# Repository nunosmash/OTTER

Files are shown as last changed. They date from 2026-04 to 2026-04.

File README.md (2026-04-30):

[README.md](https://github.com/user-attachments/files/26697365/README.md)
# OTTER

**Haptic MIDI controller** that pairs analog-feel **encoder** control with DAW integration: **Live** and **Studio** modes, **haptic** feedback, **layers** and **pages**, and a **Web Editor** (Chrome) for full configuration.

Part of the **Ash Sound Works** custom tools for live and studio — by sound artist and producer **Ash (Ahn Sunghoon)** · [GitHub](https://github.com/nunosmash) / 
[Manual](http://ashsoundworks.com/otter-manual.html)

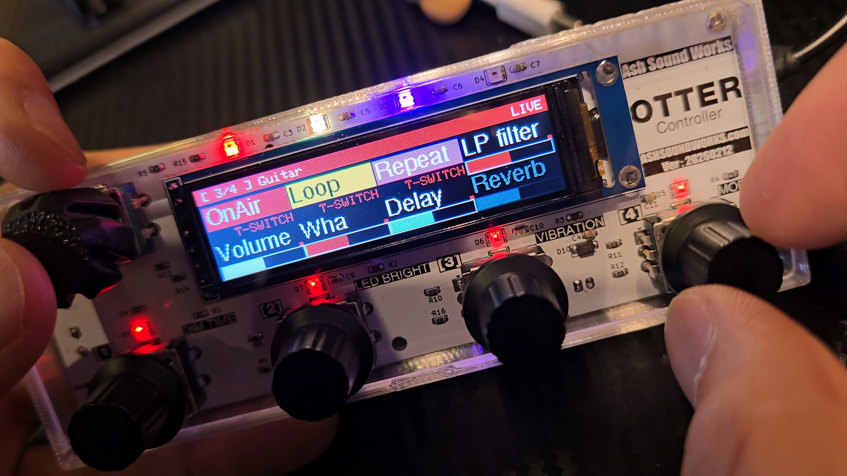
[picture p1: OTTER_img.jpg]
OTTER (https://youtu.be/qmccIaClYyg?si=hlSnW6YCaZTJ9VbL)


---

## Why OTTER?

Typical MIDI controllers struggle with the same tension: **analog pots** feel great, but mapping them to a DAW can cause **parameter jumps** encoders don’t always fix—especially when acceleration makes muscle-memory control unreliable on stage.

OTTER uses **encoders** with a **Live Mode** that maps rotation to a **fixed angular range** (like a pot), independent of spin speed, plus **haptic** cues at center (64) and at min/max (0 / 127). **Studio Mode** keeps fine resolution for production work. Bidirectional sync with the DAW and the Web Editor keeps names, colors, and lock logic aligned across sessions.

---

## Features

- **4 encoders** with push / rotate, **4 pages** — up to **32 parameter roles** (4×4×2 layers), plus multiple **global** and **button** mappings  
- **Live Mode** — rotation angle maps 1:1 with smoothing (stage-friendly, eyes-off control)  
- **Studio Mode** — speed-based acceleration for fast sweeps and fine edits  
- **Safety Lock** — auto-locks after page changes or idle; ~4 detents rotation to unlock  
- **Haptic motor** + **LED** feedback (center snap, boundary alerts); intensity: OFF / LOW / MID / HIGH  
- **USB MIDI** (class-compliant)  
- **Internal flash** + Web Editor sync for presets  
- **Web Editor** — latest **Chrome** ; connect via WebUSB  

---

## Specifications (summary)

| Item | Details |
|---|---|
| Model | OTTER |
| Controls | Global / Page encoder, Encoders 1–4 (push + rotate) |
| Pages | 4 (4 encoders × 2 layers per page → up to 32 parameters) |
| I/O | USB MIDI (class-compliant) |
| Feedback | Haptic motor, LEDs |
| Storage | Internal flash, synced with Web Editor |
| Web Editor | Chrome (latest recommended) |

---

## Basic hardware behavior

- **Rotate** — increase / decrease value  
- **Short push** — layer toggle or button action (per mapping)  
- **~4 detents rotation** — unlock **Safety Lock**  
- **Global push + bottom encoder click** — device setup (DIM time, LED brightness, vibration strength, mode)  

---

## Web Editor

1. Use **Chrome** (current version).  
2. Open the bundled **OTTER Web Editor** HTML (local file or hosted URL).  
3. Connect OTTER over USB → click **Connect** in the editor and grant device access.  
4. When the status shows **Connected**, edit and sync parameters, names, and colors.  

Editor path in the site package: `otter/OTTER Web Editor.html`

---

## Firmware update (.uf2)

OTTER uses **UF2** drag-and-drop firmware (RP2040 bootloader appears as **RPI-RP2**).

1. Connect OTTER with a **data** USB cable.  
2. Hold **Button 1** and **Button 4** together for **3+ seconds** until the **RPI-RP2** drive appears.  
3. Copy the correct **`.uf2`** file onto the drive; the device reboots when done.  

---

## Repository contents

Depending on branch or release, this repo may include:

- Firmware source  
- Web Editor assets  
- Build and flash instructions  

For full mode behavior, haptics detail, and troubleshooting, see **`otter-manual.html`** in the Ash Sound Works website bundle — add your public URL once deployed.

---

| Category | Component Description | Qty |
| :--- | :--- | :---: |
| **MCU** | Raspberry Pi Pico 2 (RP2350) | 1 |
| **Display** | 2.25" TFT LCD (ST7789, 76x284 Resolution) | 1 |
| **Encoders (Primary)** | Bourns PEC11R-4015F-S0024 | 4 |
| **Encoder (Menu)** | EC11 Rotary Encoder w/ Push Switch (Detent) | 1 |
| **Haptics** | 3V 10mm Mini Vibration Coin Motor | 1 |
| **Connectors** | PJ-320A 3.5mm Stereo Jack | 1 |
| **Capacitors** | 100μF Electrolytic Capacitor | 2 |
| **Enclosure** | 121 x 43 x 2mm Clear Acrylic Top Plate | 1 |
| **Hardware** | Custom Encoder Knobs | 5 |
| **Hardware** | Brass Heat-Set Insert Nuts (M2x2x3.2) | 4 |
| **Hardware** | M2 Phillips Head Screws (M2x4) | 4 |

---

## Documentation

- Full manual: `otter-manual.html`  
- Web Editor: `otter/OTTER Web Editor.html`  
- Other projects: [github.com/nunosmash](https://github.com/nunosmash)

---

## Disclaimer

- Use a **data-capable** USB cable for editor and firmware updates.  
- DIY builds: follow safe practice for power and assembly.

---

## License

See the `LICENSE` file in the repository root.

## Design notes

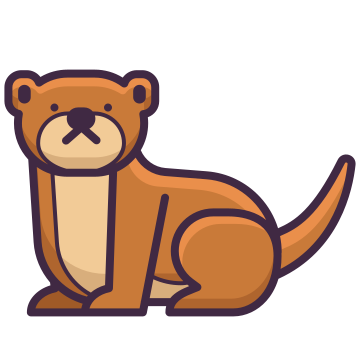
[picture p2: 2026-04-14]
Editor/otter.png

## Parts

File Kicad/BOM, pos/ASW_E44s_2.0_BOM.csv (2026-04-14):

Id | 지정자 | 풋프린트 | 수량 | 지정 | 공급자와 참조
1 | D9,D2,D3,D5,D4,D7,D1,D6,D8 | LED_WS2812B-2020_PLCC4_2.0x2.0mm | 9 | WS2812B-2020
2 |  |  | 1
3 | J3 | PJ-320A | 1 | AudioJack4
4 | J1 | PinHeader_1x08_P2.54mm_Vertical ST7789_76x284 | 1 | ST7789_76x284
5 | R2,R15,R3,R5,R4,R1 | R_0603_1608Metric | 6 | 150R
6 | Enc5 | RotaryEncoder_Alps_EC11E-Switch_Vertical_H20mm | 1 | EC11
7 | R14,R13,R10,R7,R8,R6,R16,R12,R11,R9 | R_0603_1608Metric | 10 | 330R
8 | Enc4,Enc1,Enc3,Enc2 | RotaryEncoder_Alps_EC11E-Switch_Vertical_H20mm | 4 | PEC11R-4015F-S0024
9 | C10,C9,C3,C4,C8,C11,C5,C7,C12,C6 | C_0603_1608Metric | 10 | 100n
10 | R18 | R_0603_1608Metric | 1 | 10k
11 | R17 | R_0603_1608Metric | 1 | 1k
12 | Q1 | SOT-23 | 1 | SS8050
13 | D10 | D_SOD-123 | 1 | SM4007
14 | R20 | R_0603_1608Metric | 1 | 30
15 | R19 | R_0603_1608Metric | 1 | 10
16 | J2 | JST_PH_B2B-PH-K_1x02_P2.00mm_Vertical | 1 | Motor_Socket
17 | C1,C2 | CP_Radial_D8.0mm_P3.50mm | 2 | 220uF
18 | A1 | RaspberryPi_Pico_Common_THT2 | 1 | RaspberryPi_Pico2

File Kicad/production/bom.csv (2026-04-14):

Designator | Footprint | Quantity | Value | LCSC Part #
 |  | 1
A1 | RaspberryPi_Pico_Common_THT2 | 1 | RaspberryPi_Pico2
C1, C2 | CP_Radial_D8.0mm_P3.50mm | 2 | 220uF
C10, C11, C12, C3, C4, C5, C6, C7, C8, C9 | 0603 | 10 | 100n
D1, D2, D3, D4, D5, D6, D7, D8, D9 | LED_WS2812B-2020_PLCC4_2.0x2.0mm | 9 | WS2812B-2020
D10 | D_SOD-123 | 1 | SM4007
ENC1, ENC2, ENC3, ENC4 | RotaryEncoder_Alps_EC11E-Switch_Vertical_H20mm | 4 | PEC11R-4015F-S0024
ENC5 | RotaryEncoder_Alps_EC11E-Switch_Vertical_H20mm | 1 | EC11
J1 | PinHeader_1x08_P2.54mm_Vertical ST7789_76x284 | 1 | ST7789_76x284
J2 | JST_PH_B2B-PH-K_1x02_P2.00mm_Vertical | 1 | Motor_Socket
J3 | PJ-320A | 1 | AudioJack4
Q1 | SOT-23 | 1 | SS8050
R1, R15, R2, R3, R4, R5 | 0603 | 6 | 150R
R10, R11, R12, R13, R14, R16, R6, R7, R8, R9 | 0603 | 10 | 330R
R17 | 0603 | 1 | 1k
R18 | 0603 | 1 | 10k
R19 | 0603 | 1 | 10
R20 | 0603 | 1 | 30

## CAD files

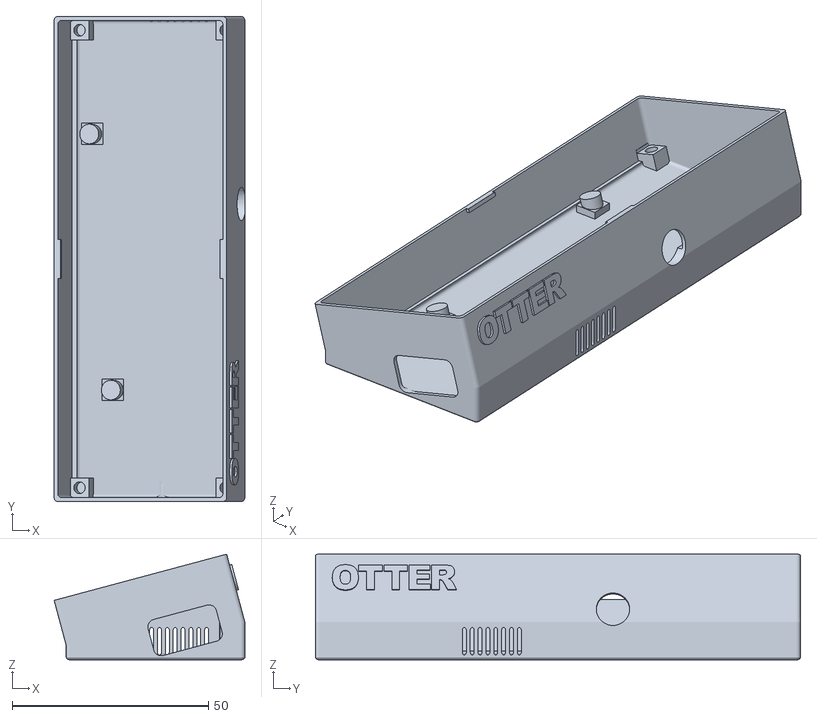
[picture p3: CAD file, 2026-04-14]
Case/OTTER case3 - 2.stl
48.6 x 123.5 x 26.9

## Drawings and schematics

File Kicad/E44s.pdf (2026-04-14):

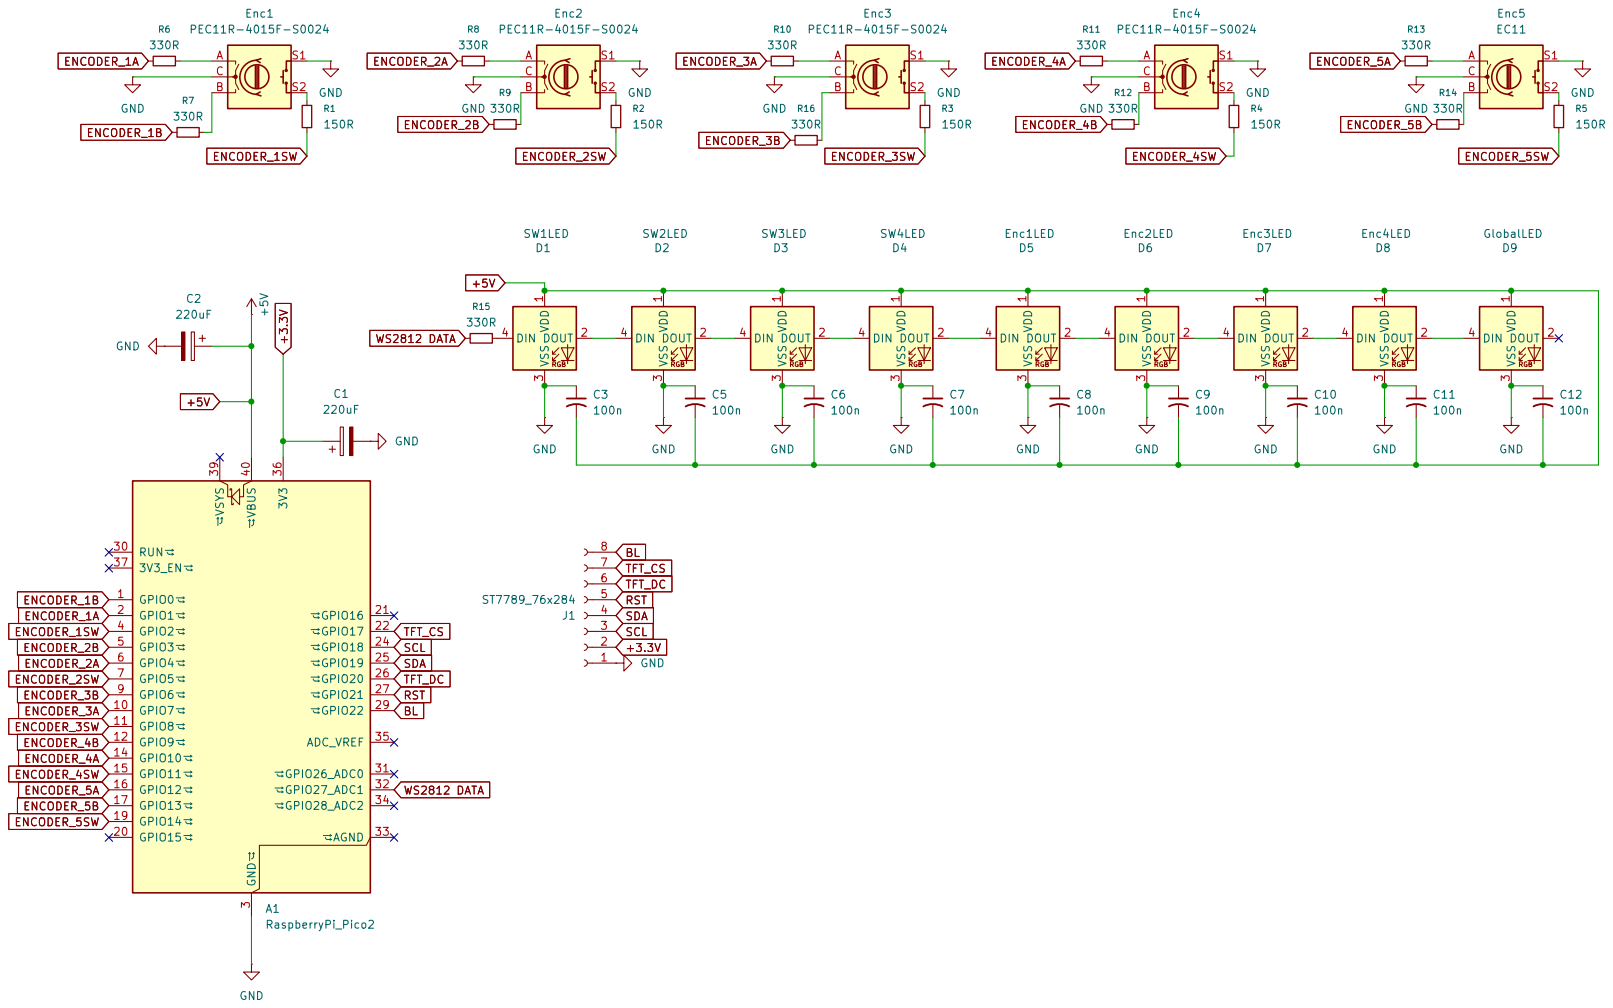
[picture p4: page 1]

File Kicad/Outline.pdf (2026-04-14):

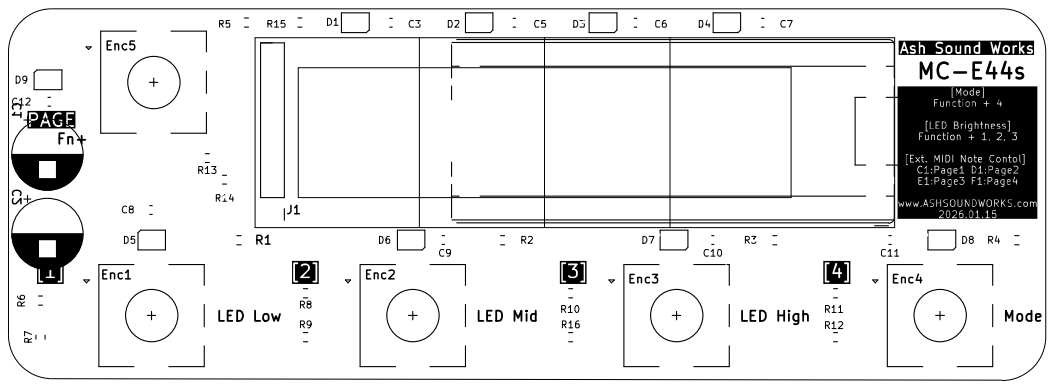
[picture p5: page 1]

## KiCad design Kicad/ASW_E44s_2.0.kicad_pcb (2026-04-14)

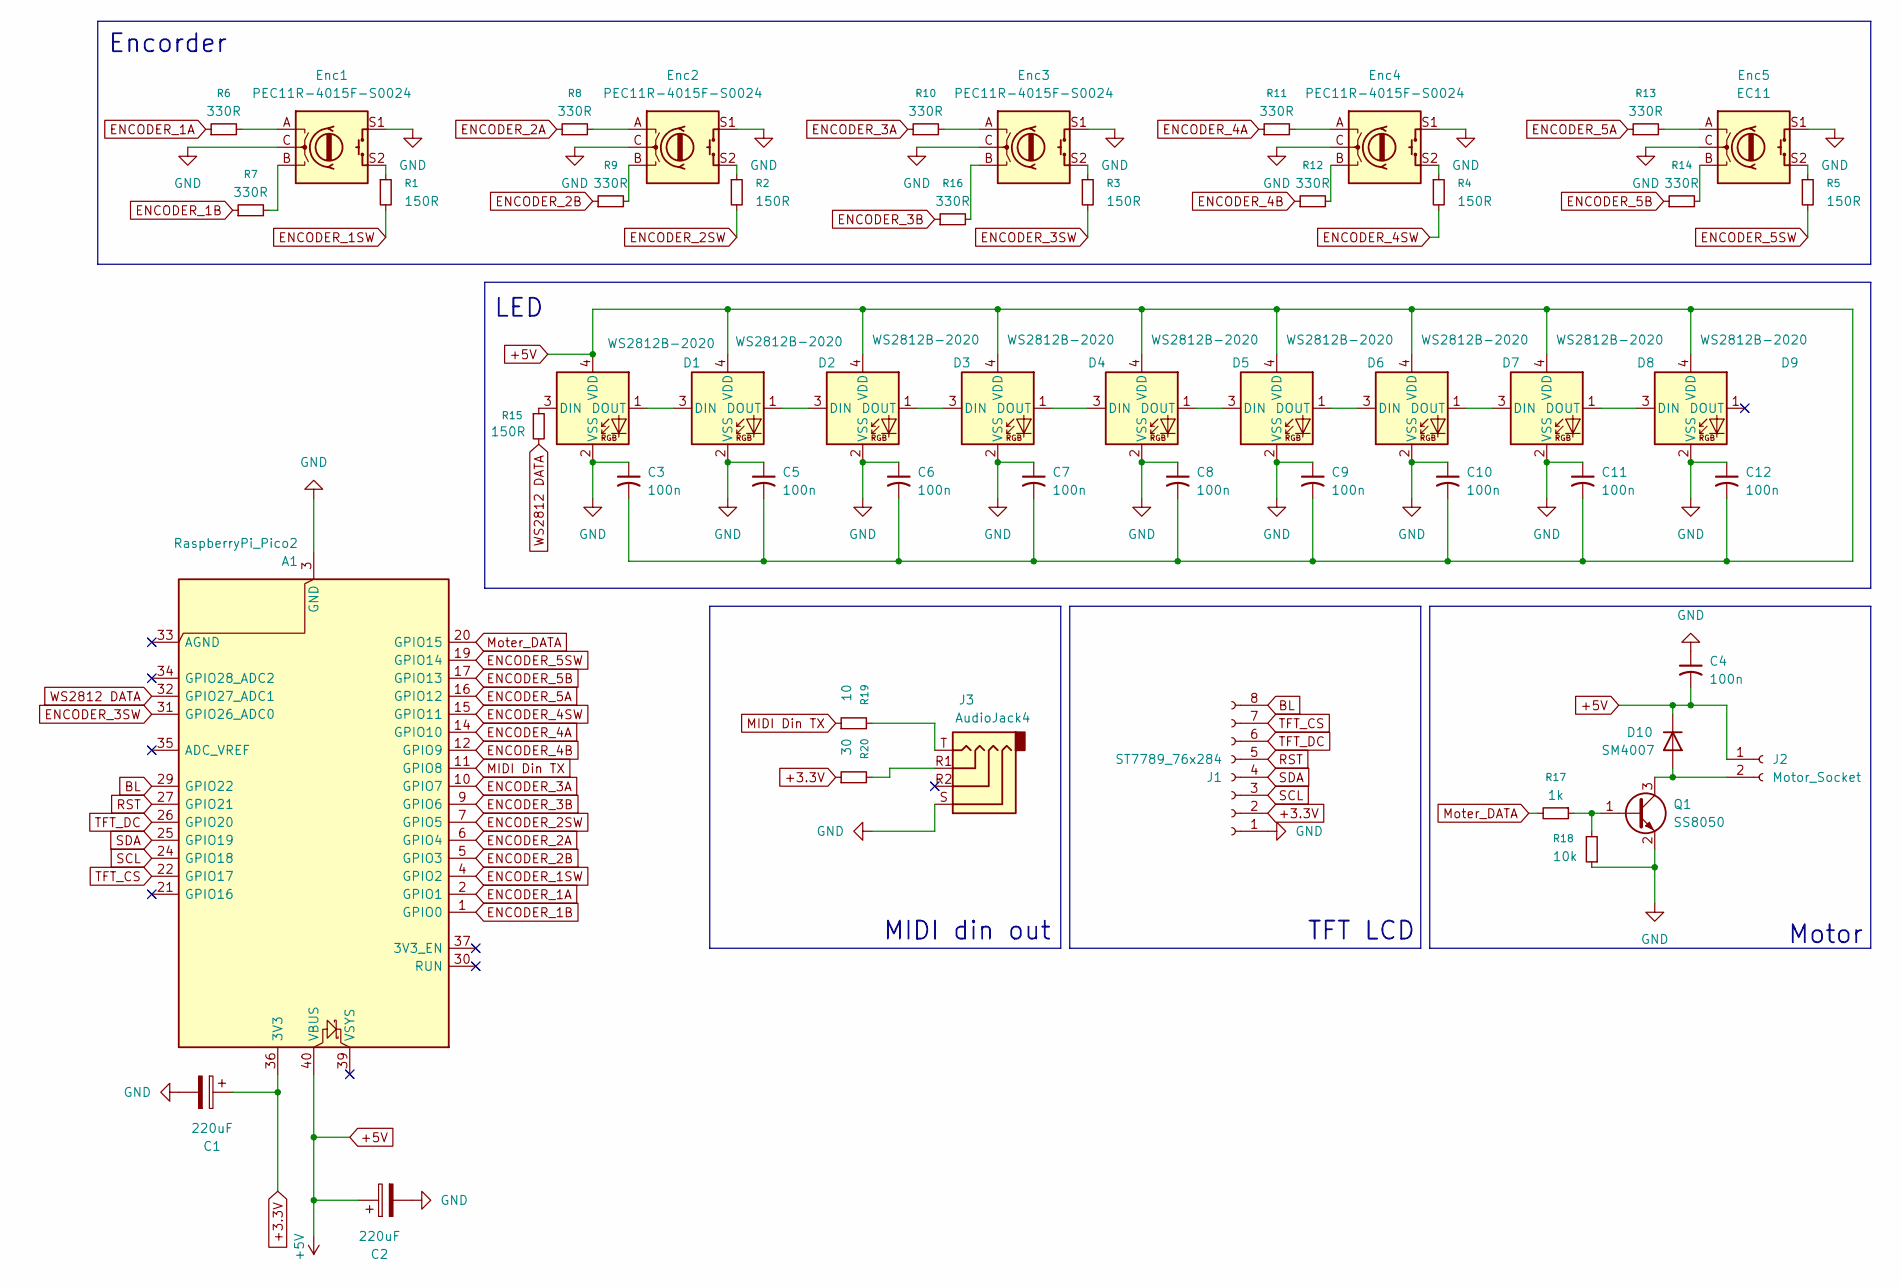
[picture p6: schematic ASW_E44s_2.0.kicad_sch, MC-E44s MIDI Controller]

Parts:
A1: RaspberryPi_Pico2; RaspberryPi_Pico_Common_THT2
C1, C2: 220uF; CP_Radial_D8.0mm_P3.50mm
C3, C4, C5, C6, C7, C8, C9, C10, C11, C12: 100n; C_0603_1608Metric
D1, D2, D3, D4, D5, D6, D7, D8, D9: WS2812B-2020; LED_WS2812B-2020_PLCC4_2.0x2.0mm
D10: SM4007; D_SOD-123
Enc1, Enc2, Enc3, Enc4: PEC11R-4015F-S0024; RotaryEncoder_Alps_EC11E-Switch_Vertical_H20mm
Enc5: EC11; RotaryEncoder_Alps_EC11E-Switch_Vertical_H20mm
J1: ST7789_76x284; PinHeader_1x08_P2.54mm_Vertical ST7789_76x284
J2: Motor_Socket; JST_PH_B2B-PH-K_1x02_P2.00mm_Vertical
J3: AudioJack4; PJ-320A
Q1: SS8050; SOT-23
R1, R2, R3, R4, R5, R15: 150R; R_0603_1608Metric
R6, R7, R8, R9, R10, R11, R12, R13, R14, R16: 330R; R_0603_1608Metric
R17: 1k; R_0603_1608Metric
R18: 10k; R_0603_1608Metric
R19: 10; R_0603_1608Metric
R20: 30; R_0603_1608Metric

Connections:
+3.3V: A1.36 (3V3), C1.1, J1.2, R20.1
+5V: A1.40 (VBUS), C2.1, C3.2, C4.2, C5.2, C6.2, C7.2, C8.2, C9.2, C10.2, C11.2, C12.2, D1.4 (VDD), D2.4 (VDD), D3.4 (VDD), D4.4 (VDD), D5.4 (VDD), D6.4 (VDD), D7.4 (VDD), D8.4 (VDD), D9.4 (VDD), D10.1 (K), J2.1
BL: A1.29 (GPIO22), J1.8
ENCODER_1A: A1.2 (GPIO1), R6.1
ENCODER_1B: A1.1 (GPIO0), R7.1
ENCODER_1SW: A1.4 (GPIO2), R1.2
ENCODER_2A: A1.6 (GPIO4), R8.1
ENCODER_2B: A1.5 (GPIO3), R9.1
ENCODER_2SW: A1.7 (GPIO5), R2.2
ENCODER_3A: A1.10 (GPIO7), R10.1
ENCODER_3B: A1.9 (GPIO6), R16.1
ENCODER_3SW: A1.31 (GPIO26_ADC0), R3.2
ENCODER_4A: A1.14 (GPIO10), R11.1
ENCODER_4B: A1.12 (GPIO9), R12.1
ENCODER_4SW: A1.15 (GPIO11), R4.2
ENCODER_5A: A1.16 (GPIO12), R13.1
ENCODER_5B: A1.17 (GPIO13), R14.1
ENCODER_5SW: A1.19 (GPIO14), R5.2
GND: A1.3 (GND), A1.8 (GND), A1.13 (GND), A1.18 (GND), A1.23 (GND), A1.28 (GND), A1.38 (GND), C1.2, C2.2, C3.1, C4.1, C5.1, C6.1, C7.1, C8.1, C9.1, C10.1, C11.1, C12.1, D1.2 (VSS), D2.2 (VSS), D3.2 (VSS), D4.2 (VSS), D5.2 (VSS), D6.2 (VSS), D7.2 (VSS), D8.2 (VSS), D9.2 (VSS), Enc1.C, Enc1.MP, Enc1.S1, Enc2.C, Enc2.MP, Enc2.S1, Enc3.C, Enc3.MP, Enc3.S1, Enc4.C, Enc4.MP, Enc4.S1, Enc5.C, Enc5.MP, Enc5.S1, J1.1, J3.S, Q1.2 (E), R18.1
MIDI Din TX: A1.11 (GPIO8), R19.1
Moter_DATA: A1.20 (GPIO15), R17.2
unnamed: D1.3 (DIN), R15.1
unnamed: D1.1 (DOUT), D2.3 (DIN)
unnamed: D2.1 (DOUT), D3.3 (DIN)
unnamed: D3.1 (DOUT), D4.3 (DIN)
unnamed: D4.1 (DOUT), D5.3 (DIN)
unnamed: D5.1 (DOUT), D6.3 (DIN)
unnamed: D6.1 (DOUT), D7.3 (DIN)
unnamed: D7.1 (DOUT), D8.3 (DIN)
unnamed: D8.1 (DOUT), D9.3 (DIN)
unnamed: D10.2 (A), J2.2, Q1.3 (C)
unnamed: Enc1.A, R6.2
unnamed: Enc1.B, R7.2
unnamed: Enc1.S2, R1.1
unnamed: Enc2.A, R8.2
unnamed: Enc2.B, R9.2
unnamed: Enc2.S2, R2.1
unnamed: Enc3.A, R10.2
unnamed: Enc3.B, R16.2
unnamed: Enc3.S2, R3.1
unnamed: Enc4.A, R11.2
unnamed: Enc4.B, R12.2
unnamed: Enc4.S2, R4.1
unnamed: Enc5.A, R13.2
unnamed: Enc5.B, R14.2
unnamed: Enc5.S2, R5.1
unnamed: J3.R1, R20.2
unnamed: J3.T, R19.2
unnamed: Q1.1 (B), R17.1, R18.2
RST: A1.27 (GPIO21), J1.5
SCL: A1.24 (GPIO18), J1.3
SDA: A1.25 (GPIO19), J1.4
TFT_CS: A1.22 (GPIO17), J1.7
TFT_DC: A1.26 (GPIO20), J1.6
WS2812 DATA: A1.32 (GPIO27_ADC1), R15.2

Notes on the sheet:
MIDI din out
Motor
LED
TFT LCD
Encorder

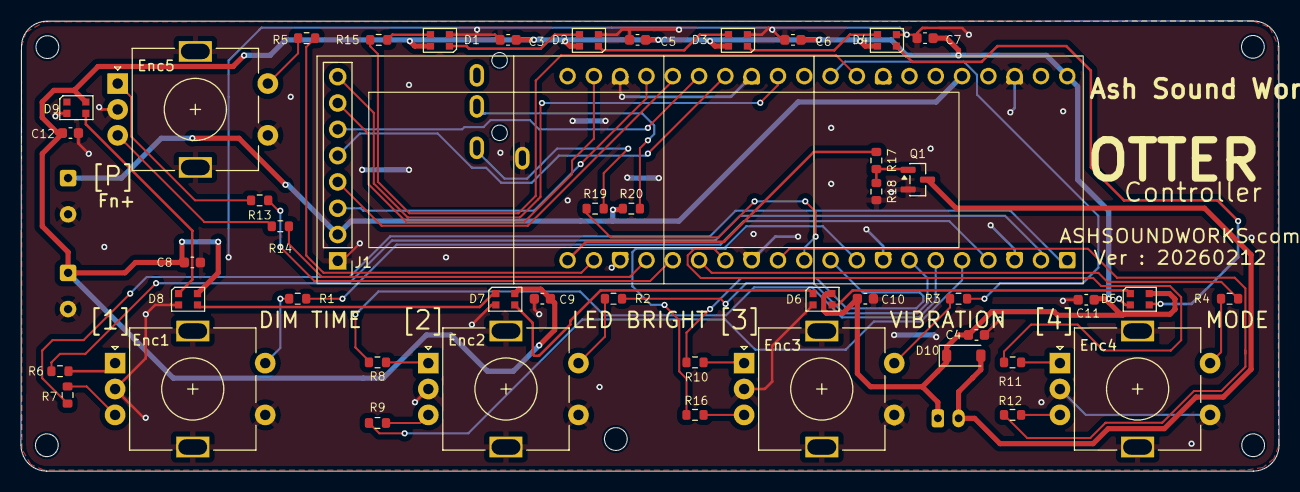
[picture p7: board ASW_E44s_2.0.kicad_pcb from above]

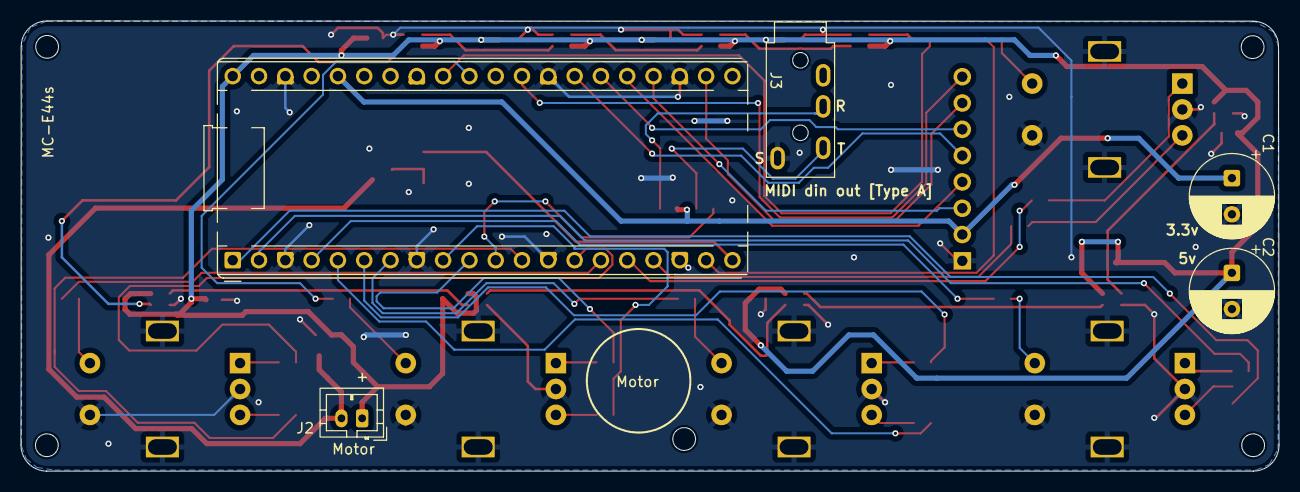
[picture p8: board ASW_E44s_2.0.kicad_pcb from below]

Board: 2 copper layers, 121.5 x 43.5 mm, 52 parts (5 on the bottom side), 55 nets.

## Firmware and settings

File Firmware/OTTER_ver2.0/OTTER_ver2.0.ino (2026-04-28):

/* 

1. 입력 및 상태 제어 (Input & Navigation)
handlePageNavigation() : 페이지 엔코더 입력 처리 및 페이지 전환/확정 로직 제어
processMainEncoders() : 4개 메인 엔코더의 회전 감지, 가속도 계산 및 MIDI 전송
handleGlobalButton() : 상단 글로벌 버튼의 상태 체크 및 지정된 MIDI CC 전송
handleEncoderSwitches() : 엔코더 클릭 감지 (일반 모드: 레이어 전환 / 설정 모드: 값 변경)
handleMidiInput() : 외부에서 들어오는 MIDI 메시지(Note/CC) 수신 및 처리

2. UI 및 피드백 (Display & Feedback)
updateUIDisplay() : 각 노브/버튼의 변경된 상태를 TFT 화면에 점진적으로 갱신
updateZone() : 화면의 특정 구역(상단/하단)을 다시 그려주는 실질적인 UI 렌더링
drawStaticLayout() : 현재 페이지의 전체 틀(가이드라인, 라벨명 등)을 화면에 출력
drawPreviewAnimated() : 페이지 전환 시 부드러운 애니메이션 효과 구현
drawSettingUI() : 글로벌 설정 변경 시 나타나는 중앙 팝업 UI 생성
handleVisualFlash() : 센터 도달이나 한계값 터치 시 LED/UI가 깜빡이는 효과 제어

3. 시스템 유지관리 (System & Logic)
handleSystemMaintenance() : 절전 모드, 진동 정지 타이머, 시리얼 통신, 페이지 자동 저장 관리
loadConfig() : 플래시 메모리(LittleFS)에서 설정값 및 마지막 페이지 로드
saveSystemSettings() : 현재 설정 및 페이지 번호를 JSON 파일로 플래시 메모리에 저장
syncEncodersToPage() : 페이지 변경 시 해당 페이지의 MIDI 값들을 엔코더 변수에 동기화
stabilizeAfterPageChange() : 페이지 전환 직후 원치 않는 입력을 방지하기 위한 안정화 로직
userActivity() : 모든 사용자 조작 시 호출되어 절전 모드 타이머를 초기화

*/

#include <Adafruit_TinyUSB.h>
#include <Adafruit_GFX.h>
#include <Adafruit_ST7789.h>
#include <Adafruit_NeoPixel.h>
#include <SPI.h>
#include <Fonts/FreeSans9pt7b.h>
#include <LittleFS.h>
#include <ArduinoJson.h>
#include <hardware/watchdog.h>
#include "pico/bootrom.h"

#define MY_USB_MANUFACTURER "ASH SOUND WORKS"
#define MY_USB_PRODUCT "OTTER"   // 기기 B는 B로 변경
#define MY_USB_PID 0x044B        // 기기 B는 0x044B로 변경
#define MY_USB_SERIAL "MC-E44s"  // 시리얼도 다르게!

// 1. TFT 및 핀 설정
#define TFT_CS 17
#define TFT_DC 20
#define TFT_RST 21
#define TFT_BL 22
#define TFT_SCL 18
#define TFT_SDA 19

Adafruit_ST7789 tft = Adafruit_ST7789(TFT_CS, TFT_DC, TFT_RST);
GFXcanvas16 canvas(284, 22);

// -------LED 설정 수정
#define LED_PIN 27
#define LED_COUNT 9  // 2020(4) + 5050(4) + 5050(1)
Adafruit_NeoPixel pixels(LED_COUNT, LED_PIN, NEO_GRB + NEO_KHZ800);

#define MIDI_UART uart1
#define MIDI_TX_PIN 8


// 인덱스 정의 (가독성용)
#define LED_IDX_BTN_START 0  // 0, 1, 2, 3 (2020 스트립)
#define LED_IDX_ENC_START 4  // 4, 5, 6, 7 (엔코더 위 5050)
#define LED_IDX_GLOBAL 8     // 8 (페이지 엔코더 옆 5050)

#define NUM_ENCODERS 4
const uint8_t pinA[NUM_ENCODERS] = { 1, 4, 7, 10 };
const uint8_t pinB[NUM_ENCODERS] = { 0, 3, 6, 9 };
const uint8_t pinSW[NUM_ENCODERS] = { 2, 5, 26, 11 };

#define PAGE_ENC_A 13
#define PAGE_ENC_B 12
#define GLOBAL_BTN_PIN 14

#define VIB_MOTOR_PIN 15  // 진동 모터 핀 번호

unsigned long pressStartTime = 0;  // 버튼이 눌리기 시작한 시간 저장
bool isEnteringBootloader = false;

unsigned long vibStopTime = 0;
bool isVibrating = false;

Adafruit_USBD_MIDI usb_midi;
// 컴파일러가 USB 장치 정보를 읽어갈 때 사용하는 콜백 함수들
const uint16_t *tud_descriptor_product_cb(void) {
  static uint16_t _desc_str[32];
  uint8_t chr_len = strlen(MY_USB_PRODUCT);
  if (chr_len > 31) chr_len = 31;  // 안전장치 추가
  _desc_str[0] = (TUSB_DESC_STRING << 8) | (2 * chr_len + 2);
  for (uint8_t i = 0; i < chr_len; i++) _desc_str[i + 1] = MY_USB_PRODUCT[i];
  return _desc_str;
}

const uint16_t *tud_descriptor_manufacturer_cb(void) {
  static uint16_t _desc_str[32];
  uint8_t chr_len = strlen(MY_USB_MANUFACTURER);
  if (chr_len > 31) chr_len = 31;
  _desc_str[0] = (TUSB_DESC_STRING << 8) | (2 * chr_len + 2);
  for (uint8_t i = 0; i < chr_len; i++) _desc_str[i + 1] = MY_USB_MANUFACTURER[i];
  return _desc_str;
}

const uint16_t *tud_descriptor_serial_cb(void) {
  static uint16_t _desc_str[32];
  uint8_t chr_len = strlen(MY_USB_SERIAL);
  if (chr_len > 31) chr_len = 31;
  _desc_str[0] = (TUSB_DESC_STRING << 8) | (2 * chr_len + 2);
  for (uint8_t i = 0; i < chr_len; i++) _desc_str[i + 1] = MY_USB_SERIAL[i];
  return _desc_str;
}

// 2. 데이터 구조
struct Pot {
  char knobName[16];
  uint8_t knobChannel, knobCC;
  char knobColorCode;
  char btnName[16];
  uint8_t btnChannel, btnCC;
  char btnColorCode;
  bool isToggle;
  char mode;
  uint8_t activeLayer;
  uint8_t knobValue;
  uint8_t btnCcValue;
  bool btnState;
  bool needsUpdateUpper;
  bool needsUpdateLower;

  Pot() {
    memset(knobName, 0, 16);
    memset(btnName, 0, 16);
    knobValue = 64;
    btnCcValue = 64;
    btnState = false;
    activeLayer = 0;
    needsUpdateUpper = true;
    needsUpdateLower = true;
  }
};

struct PageConfig {
  char title[20];
  char colorCode;
};
#define NUM_PAGES 4
#define POTS_PER_PAGE 4

Pot pots[NUM_PAGES][POTS_PER_PAGE];
PageConfig pageSettings[NUM_PAGES];

struct GlobalBtnConfig {
  char name[16];
  uint8_t channel, cc;
  bool isToggle, state;
};
GlobalBtnConfig globalBtn;

// ==========================================
// [OTTER System Configurations & Variables]
// ==========================================

// --- 시스템 및 절전 설정 ---
unsigned long DIM_TIMEOUT = 300000;        // 화면 자동 절전 시간 (ms, 기본 5분)
bool startInStudio = false;                // 시작 시 스튜디오 모드 여부
int currentBrightness = 0;                 // 현재 밝기 (0: Full, 255: Dark)
int targetBrightness = 0;                  // 목표 밝기 (페이드 효과용)
unsigned long lastFadeTime = 0;            // 밝기 전환 타이머
unsigned long lastAnyInteractionTime = 0;  // 마지막 조작 시간 (절전 체크용)
bool isLedOn = true;                       // LED 활성화 상태 플래그
volatile bool pageEncoderReverse = false;   // 페이지 엔코더 A/B 배선 반대 보정 (에디터 pageEncRev)

// --- 페이지 및 상태 관리 ---
bool justChangedPage = false;                  // 페이지 전환 직후 플래그
int currentPage = 0, previewPage = 0;          // 현재 페이지 및 전환 예고 페이지
bool isStudioMode = false;                     // 운영 모드 (False: Live, True: Studio)
bool isPagePending = false;                    // 페이지 확정 대기 상태
unsigned long lastPageMoveTime = 0;            // 마지막 페이지 이동 시간
unsigned long lastUiUpdateTime = 0;            // UI 갱신 타이머
const unsigned long PAGE_CONFIRM_DELAY = 800;  // 페이지 확정 대기 시간 (ms)
unsigned long lastPageChangeTime = 0;          // 마지막 페이지 변경 시점 저장
bool pageNeedsSave = false;                    // 저장 필요 여부 플래그

// --- 메인 엔코더 데이터 (4개) ---
volatile uint8_t encState[NUM_ENCODERS] = { 0 };
long targetLong[NUM_ENCODERS] = { 6400, 6400, 6400, 6400 };   // 목표 MIDI값 (x100 해상도)
long currentLong[NUM_ENCODERS] = { 6400, 6400, 6400, 6400 };  // 현재 MIDI값 (x100 해상도)
int currentMidi[NUM_ENCODERS] = { 64, 64, 64, 64 };           // 현재 MIDI 정수값 (0-127)
unsigned long lastDetentTime[NUM_ENCODERS] = { 0 };           // 마지막 엔코더 물리 멈춤 시간
unsigned long lastTickTime[NUM_ENCODERS] = { 0 };             // 마지막 인터럽트 발생 시간
float speedBlend[NUM_ENCODERS] = { 0 };                       // 가속도 계산용 블렌드값

// --- 인코더 잠금(Lock) 메커니즘 ---
bool isRotLocked[NUM_ENCODERS] = { false };  // 현재 엔코더 잠금 상태
int lockAccumulator[NUM_ENCODERS] = { 0 };   // 잠금 해제를 위한 회전 누적치
const int ROT_THRESHOLD = 4;                 // 잠금 해제 임계값 (클릭 수)
const unsigned long LOCK_TIMEOUT = 4000;     // 자동 잠금 대기 시간 (4초)

// --- 시각적 피드백 (LED/LCD Flash) ---
uint8_t flashCount[8] = { 0 };           // 깜빡임 횟수 (0-3: 상단, 4-7: 하단)
unsigned long lastFlashTime[8] = { 0 };  // 마지막 깜빡임 시간
bool isFlashOn[8] = { false };           // 현재 깜빡임 상태 (On/Off)

// --- 엔코더 스위치 및 디바운스 ---
bool lastSwState[NUM_ENCODERS] = { HIGH, HIGH, HIGH, HIGH };
unsigned long swDebounceTime[NUM_ENCODERS] = { 0 };
const unsigned long BTN_DEBOUNCE_TIME = 25;  // 버튼 디바운스 시간 (ms)

// --- UI 및 내비게이션 관련 ---
int currentUiIndex = 0;                // 루프 내 점진적 UI 갱신 인덱스
volatile int pageStepAccumulator = 0;  // 페이지 엔코더 회전 누적
volatile int lastPageEncA = HIGH;      // 페이지 엔코더 A상 상태
const int PAGE_ENC_THRESHOLD = 2;      // 페이지 전환 감도
int animDirection = 1;                 // 페이지 전환 애니메이션 방향
int lastDrawnPage = -1;                // 마지막으로 그려진 페이지 번호

// --- MIDI 입출력 보조 ---
uint8_t lastSentValue[128] = { 255 };     // 마지막으로 전송된 CC 데이터 캐시
unsigned long lastMoveTime[8] = { 0 };    // 각 파라미터별 마지막 조작 시간
unsigned long globalBtnDebounceTime = 0;  // 글로벌 버튼 디바운스 타이머
int liveStepAccum[NUM_ENCODERS] = { 0 };  // 라이브 모드 전용 보간 누적기
unsigned long ignoreMidiUntil = 0;        // 수신 무시 타이머 (충돌 방지)

// --- 스마트 스무딩 (저속 구간) ---
int sentMidi[NUM_ENCODERS];                // 실제 전송된 마지막 MIDI 값
unsigned long nextStepTime[NUM_ENCODERS];  // 다음 보간 스텝 예정 시간
bool isSlowMove[NUM_ENCODERS];             // 저속 회전 상태 판별
static unsigned long lastMidiSendTime[NUM_ENCODERS];

// --- 하드웨어 밝기 및 LED 설정 ---
uint8_t globalBrightness = 40;  // NeoPixel 밝기 (기본 15)
const uint8_t BRIGHTNESS_MIN = 10;
const uint8_t BRIGHTNESS_MAX = 20;
float currentDimRatio = 0.15f;      // 절전 시 밝기 배율
float globalLedMultiplier = 0.10f;  // 전체 LED 광량 계수

// --- 시스템 설정 모드 (Setting UI) ---
bool isSettingTimeout = false;                                // 설정 모드 활성화 상태
unsigned long settingDisplayTime = 0;                         // 설정 화면 유지 시간 체크
const int TIMEOUT_STEPS[] = { 1, 3, 5, 10, 20, 30, 40, 60 };  // 절전 시간 옵션
int currentTimeoutIdx = 1;                                    // 현재 선택된 절전 시간 인덱스
bool settingsChanged = false;                                 // 설정 변경 여부 (저장 트리거)

// --- 피드백 상태 (진동/센터) ---
static bool isAtLimit[8] = { false };   // 끝값(0/127) 도달 상태
static bool isAtCenter[8] = { false };  // 센터(64) 진입 상태
int vibStrengthMax = 160;               // 진동 모터 최대 강도
float rainbowHue = 0;                   // 6번 LED 레인보우 효과용

// ==========================================

// ===============================
// 유틸리티 및 그래픽 루틴
// ===============================

uint16_t getColor(char c) {
  switch (c) {
    case 'R': return 0xF000;  // Neon Crimson (밝고 진한 레드)
    case 'G': return 0x0740;  // Neo Emerald (생기 있는 에메랄드)
    case 'B': return 0x341F;  // Electric Sky (밝은 일렉트릭 블루)
    case 'Y': return 0xFFE0;  // Luminous Amber (빛나는 앰버)
    case 'M': return 0xF01F;  // Vivid Magenta (팝한 핑크 마젠타)
    case 'C': return 0x07FF;  // Ice Cyan (네온 청록)
    case 'O': return 0xFD00;  // Neon Orange (선명한 오렌지)
    case 'W': return 0xFFFF;  // Pure White
    default: return 0x07FF;
  }
}

// 네오픽셀용 RGB 색상을 반환하는 함수
uint32_t getLEDColor(char c) {
  switch (c) {
    case 'R':
      return pixels.Color(255, 5, 5);  // Neon Crimson 느낌: 순수 레드보다 살짝 핑크빛이 도는 진한 레드
    case 'G':
      return pixels.Color(40, 240, 40);  // Neo Emerald 느낌: 초록에 청록을 살짝 섞어 생기 있는 에메랄드 톤
    case 'B':
      return pixels.Color(0, 50, 255);  // Electric Sky 느낌: 너무 어두운 파랑이 아닌, 밝고 시원한 스카이 블루
    case 'Y':
      return pixels.Color(255, 190, 0);  // Luminous Amber 느낌: 노랑보다 오렌지 쪽으로 더 깊은 따뜻한 앰버
    case 'M':
      return pixels.Color(200, 10, 250);  // Vivid Magenta 느낌: 보라색보다는 팝한 핫핑크 톤
    case 'C':
      return pixels.Color(0, 255, 150);  // Ice Cyan 느낌: 형광 느낌이 나는 시원한 민트-사이언 톤
    case 'O':
      return pixels.Color(255, 100, 5);  // Neon Orange 느낌: 붉은 기가 도는 선명하고 진한 오렌지
    case 'W':
      return pixels.Color(140, 140, 140);  // 보정된 White: 눈부심을 줄이고 살짝 푸른기를 돌아 더 깨끗해 보이는 흰색
    default:
      return pixels.Color(0, 255, 150);  // 기본값 (Ice Cyan 계열)
  }
}

uint16_t getDimColor(uint16_t color) {
  return (((color & 0xF800) >> 1) & 0x7800) | (((color & 0x07E0) >> 1) & 0x03E0) | (((color & 0x001F) >> 1) & 0x000F);
}

uint16_t getContrastColor(char colorCode) {
  if (colorCode == 'W' || colorCode == 'Y' || colorCode == 'C' || colorCode == 'A' || colorCode == 'G') return 0x0000;
  return 0xFFFF;
}

// 함수 위치는 setup() 위쪽 어디든 상관없습니다.
void pageEncISR() {
  int a = digitalRead(PAGE_ENC_A);
  int b = digitalRead(PAGE_ENC_B);

  if (a != lastPageEncA) {
    int step = (b != a) ? 1 : -1;
    if (pageEncoderReverse) step = -step;
    pageStepAccumulator += step;
  }
  lastPageEncA = a;
}

void triggerFlash(int i) {
  flashCount[i] = 6;  // 6번 반전 = 3번 깜빡임
  lastFlashTime[i] = millis();
  isFlashOn[i] = true;

  // UI 갱신 예약 (이미 있는 코드일 것입니다)
  if (i < 4) pots[currentPage][i].needsUpdateUpper = true;
  else pots[currentPage][i - 4].needsUpdateLower = true;
}

//모든 사용자 조작 시 호출되어 절전 모드 타이머를 초기화
void userActivity() {
  lastAnyInteractionTime = millis();
  targetBrightness = 0;
}

void updateLabelName(int i, bool isUpper) {
  Pot &p = pots[currentPage][i];
  int x = 2 + i * 70;
  tft.setFont(&FreeSans9pt7b);
  if (isUpper) {
    if (p.mode == 'E') {
      tft.setTextColor((p.activeLayer == 1) ? 0xFFFF : 0x8CF1);
      tft.fillRect(x, 15, 70, 20, 0x0000);
      tft.setCursor(max(0, x + 1), 29);
      tft.print(p.btnName);
    }
  } else {
    tft.setTextColor((p.mode == 'E' && p.activeLayer != 0) ? 0x8CF1 : 0xFFFF);
    tft.fillRect(x, 44, 70, 20, 0x0000);
    tft.setCursor(x + 1, 59);
    tft.print(p.knobName);
  }
}


void renderGauge(int i, bool isUpper) {
  Pot &p = pots[currentPage][i];
  int fIdx = isUpper ? i : i + 4;
  int value = isUpper ? p.btnCcValue : p.knobValue;
  unsigned long now = millis();
  int x = 2 + i * 70;
  int y = isUpper ? 35 : 65;

  bool isActive = isUpper ? (p.activeLayer == 1) : (p.mode == 'S' || p.activeLayer == 0);
  char colorC = isUpper ? p.btnColorCode : p.knobColorCode;
  int w = map(value, 0, 127, 0, 68);

  // 숫자 표시 조건
  bool showNumber = !justChangedPage && (isStudioMode || (now - lastMoveTime[fIdx] < 2000));

  // 업데이트가 필요 없는 상황이면 리턴
  if (!p.needsUpdateUpper && !p.needsUpdateLower && !showNumber && flashCount[fIdx] == 0) {
    return;
  }
  uint16_t border = isActive ? 0xCE79 : 0x4208;
  uint16_t barColor = isActive ? getColor(colorC) : getDimColor(getColor(colorC));
  int tempW = w;

  if (flashCount[fIdx] > 0 && isFlashOn[fIdx]) {
    border = 0xF800;
    if (value == 127) barColor = 0x4208;
    else if (value == 0) {
      barColor = 0x8410;
      tempW = 68;
    }
  }

  tft.startWrite();

  // 1. 게이지 테두리
  tft.drawRect(x, y - 1, 70, 11, border);

  // 2. [수정] 잠금 표시 점 로직
  // 잠겨있고(isRotLocked) + 현재 활성화된 바(isActive)일 때만 점을 표시함
  if (isRotLocked[i] && isActive) {
    // 현재 페이지의 설정 색상 코드를 가져와서 실제 16비트 색상으로 변환
    uint16_t pageThemeColor = getColor(pageSettings[currentPage].colorCode);

    // x + 33: 정중앙 위치, y - 4: 테두리 바로 위
    tft.fillRect(x + 67, y - 4, 3, 3, pageThemeColor);
  } else {
    // 잠금이 풀렸거나 비활성이면 검은색으로 지움
    tft.fillRect(x + 67, y - 4, 3, 3, 0x0000);
  }

  // 3. 게이지 바 채우기
  tft.fillRect(x + 1, y, tempW, 9, barColor);
  tft.fillRect(x + 1 + tempW, y, 68 - tempW, 9, 0x0000);

  // 4. 숫자 표시 로직
  if (showNumber) {
    char buf[4];
    itoa(value, buf, 10);
    int len = strlen(buf);
    int startX = (x + 70) - 4 - (len * 6);
    tft.setFont(NULL);
    tft.setTextSize(1);
    for (int n = 0; n < len; n++) {
      int charX = startX + (n * 6);
      bool isUnderBar = (tempW > (charX - x + 2));
      uint16_t txtColor = 0xFFFF;
      if (isActive) {
        bool isBrightBar = (colorC == 'Y' || colorC == 'W' || colorC == 'G' || colorC == 'C') || (flashCount[fIdx] > 0 && isFlashOn[fIdx] && value == 0);
        if (isUnderBar && isBrightBar) txtColor = 0x0000;
        else if (!isUnderBar) txtColor = 0xC618;
      } else {
        txtColor = 0x52AA;
      }
      tft.setTextColor(txtColor, isUnderBar ? barColor : 0x0000);
      tft.setCursor(charX, y + 1);
      tft.print(buf[n]);
    }
  }
  tft.endWrite();

  if (isUpper) p.needsUpdateUpper = false;
  else p.needsUpdateLower = false;
}

//화면의 특정 구역(상단/하단)을 다시 그려주는 실질적인 UI 렌더링
void updateZone(int i, bool isUpper) {
  Pot &p = pots[currentPage][i];
  int x = 2 + i * 70;
  if (isUpper && p.mode != 'E') {
    tft.fillRect(x, 15, 69, 19, p.btnState ? getColor(p.btnColorCode) : 0x0000);
    tft.setFont(&FreeSans9pt7b);
    tft.setTextColor(p.btnState ? getContrastColor(p.btnColorCode) : 0x8CF1);
    tft.setCursor(max(0, x + 1), 29);
    tft.print(p.btnName);
    tft.setFont(NULL);
    tft.setTextColor(getColor(pageSettings[currentPage].colorCode));
    tft.setCursor(x + 21, 36);
    tft.print(p.isToggle ? "T-SWITCH" : "M-SWITCH");
    p.needsUpdateUpper = false;
  } else {
    renderGauge(i, isUpper);
  }
}

void updateModeDisplay() {
  PageConfig &cfg = pageSettings[currentPage];
  tft.fillRect(240, 0, 44, 12, getColor(cfg.colorCode));
  tft.setFont(NULL);
  tft.setTextColor(getContrastColor(cfg.colorCode));
  int yOffset = (cfg.colorCode == 'B') ? 2 : 3;
  tft.setCursor(245, yOffset);
  tft.print(isStudioMode ? "STUDIO" : "  LIVE");
}

//현재 페이지의 전체 틀(가이드라인, 라벨명 등)을 화면에 출력
void drawStaticLayout() {
  tft.fillScreen(0x0000);
  PageConfig &cfg = pageSettings[currentPage];
  uint16_t themeCol = getColor(cfg.colorCode);
  uint16_t contrastCol = getContrastColor(cfg.colorCode);

  // 1. 상단 기본 바 배경 및 페이지 정보
  tft.fillRect(0, 0, 284, 12, themeCol);
  tft.setFont(NULL);
  tft.setTextSize(1);
  tft.setTextColor(contrastCol);

  int yOffset = (cfg.colorCode == 'B') ? 2 : 3;
  tft.setCursor(5, yOffset);
  tft.print("[ ");
  tft.print(currentPage + 1);
  tft.print("/4 ] ");
  tft.print(cfg.title);

  // 2. 글로벌 버튼 상태 복구 (중복 제거 → 함수 호출)
  drawGlobalBtnUI();

  // 3. 포트별 이름 및 게이지 출력
  for (int i = 0; i < 4; i++) {
    updateLabelName(i, true);
    updateLabelName(i, false);
    updateZone(i, true);
    updateZone(i, false);
  }
}

//페이지 전환 시 부드러운 애니메이션 효과 구현
void drawPreviewAnimated() {
  // 1. 입구 컷 방지: 마지막에 그린 페이지와 지금 그리려는 페이지가 같고, 조작도 없다면 정지만 유지
  if (lastDrawnPage == previewPage && pageStepAccumulator == 0) {
    PageConfig &pCfg = pageSettings[previewPage];
    uint16_t pBarCol = getColor(pCfg.colorCode);
    uint16_t pTextCol = getContrastColor(pCfg.colorCode);

    int numW = (previewPage + 1 >= 10) ? 24 : 12;
    int totalW = 30 + numW + 18 + (int)(strlen(pCfg.title) * 12);
    int startX = (284 - totalW) / 2;

    // 캔버스에 그리기 (Y좌표는 27을 뺀 상대 좌표로 계산: 35->8, 30->3)
    canvas.fillScreen(0x0000);
    canvas.fillRect(0, 0, 284, 22, pBarCol);
    canvas.setTextColor(pTextCol);
    canvas.setTextSize(1);
    canvas.setCursor(startX, 8);
    canvas.print("Page");
    canvas.setTextSize(2);
    canvas.setCursor(startX + 30, 3);
    canvas.print(previewPage + 1);
    canvas.setTextSize(1);
    canvas.setCursor(startX + 30 + numW, 8);
    canvas.print(" -  ");
    canvas.setTextSize(2);
    canvas.setCursor(startX + 30 + numW + 18, 3);
    canvas.print(pCfg.title);

    // 도장 찍기! (0, 27) 위치에 한 번에 출력
    tft.drawRGBBitmap(0, 27, canvas.getBuffer(), 284, 22);
    return;
  }

  // 2. 애니메이션 준비
  tft.fillScreen(0x0000);
  tft.setTextWrap(false);

  int sourcePage = (lastDrawnPage == -1) ? currentPage : lastDrawnPage;
  PageConfig &oldCfg = pageSettings[sourcePage];
  PageConfig &newCfg = pageSettings[previewPage];
  uint16_t oldBarCol = getColor(oldCfg.colorCode);
  uint16_t newBarCol = getColor(newCfg.colorCode);
  uint16_t oldTextCol = getContrastColor(oldCfg.colorCode);
  uint16_t newTextCol = getContrastColor(newCfg.colorCode);

  auto getFullWidthSize2 = [](int pageNum, const char *title) {
    int numW = (pageNum >= 10) ? 24 : 12;
    return 30 + numW + 18 + (int)(strlen(title) * 12);
  };

  int oldStartX = (284 - getFullWidthSize2(sourcePage + 1, oldCfg.title)) / 2;
  int newStartX = (284 - getFullWidthSize2(previewPage + 1, newCfg.title)) / 2;

  const int totalSteps = 7;  // 프레임 수를 7로 유지

  for (int i = 0; i <= totalSteps; i++) {
    // 탈출 조건
    if (i > 0 && abs(pageStepAccumulator) >= (PAGE_ENC_THRESHOLD + 1)) {
      tft.setTextSize(1);
      return;
    }

    int slidePos = (i * 284) / totalSteps;
    int newX = (animDirection == 1) ? (-284 + slidePos) : (284 - slidePos);
    int oldX = (animDirection == 1) ? (slidePos) : (-slidePos);

    tft.startWrite();

    // --- 나가는 페이지 (Old Page) ---
    if (sourcePage != previewPage && oldX > -284 && oldX < 284) {
      canvas.fillScreen(0x0000);
      canvas.fillRect(0, 0, 284, 22, oldBarCol);
      canvas.setTextColor(oldTextCol);
      canvas.setTextSize(1);
      canvas.setCursor(oldStartX, 8);
      canvas.print("Page");
      canvas.setTextSize(2);
      canvas.setCursor(oldStartX + 30, 3);
      canvas.print(sourcePage + 1);
      int numW = (sourcePage + 1 >= 10) ? 24 : 12;
      canvas.setTextSize(1);
      canvas.setCursor(oldStartX + 30 + numW, 8);
      canvas.print(" -  ");
      canvas.setTextSize(2);
      canvas.setCursor(oldStartX + 30 + numW + 18, 3);
      canvas.print(oldCfg.title);

      tft.drawRGBBitmap(oldX, 27, canvas.getBuffer(), 284, 22);
    }

    // --- 들어오는 페이지 (New Page) ---
    if (newX > -284 && newX < 284) {
      canvas.fillScreen(0x0000);
      canvas.fillRect(0, 0, 284, 22, newBarCol);
      canvas.setTextColor(newTextCol);
      canvas.setTextSize(1);
      canvas.setCursor(newStartX, 8);
      canvas.print("Page");
      canvas.setTextSize(2);
      canvas.setCursor(newStartX + 30, 3);
      canvas.print(previewPage + 1);
      int numW = (previewPage + 1 >= 10) ? 24 : 12;
      canvas.setTextSize(1);
      canvas.setCursor(newStartX + 30 + numW, 8);
      canvas.print(" -  ");
      canvas.setTextSize(2);
      canvas.setCursor(newStartX + 30 + numW + 18, 3);
      canvas.print(newCfg.title);

      tft.drawRGBBitmap(newX, 27, canvas.getBuffer(), 284, 22);
    }

    tft.endWrite();
    delay(7);  // 8ms 딜레이 유지
  }

  lastDrawnPage = previewPage;
  tft.setTextWrap(true);
  tft.setTextSize(1);
}
// ===============================
// JSON 및 설정 관리
// ===============================
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
void loop() {
  watchdog_update();
  unsigned long now = millis();

  handleSystemMaintenance(now);  // 시리얼, 부트셀, 절전, 진동 타이머
  handleMidiInput();             // 외부 MIDI 수신
  handlePageNavigation(now);     // 페이지 인코더 및 설정 모드 복구(타이머 종료) 로직

  // 1. 버튼 입력은 '설정 모드 중'에도 계속 읽어야 하므로 조건문 밖으로 뺍니다.
  if (!isPagePending) {
    handleEncoderSwitches(now);
  }

  // 2. 나머지 로직(인코더 회전, 일반 UI 갱신 등)은 설정 모드가 아닐 때만 수행합니다.
  if (!isSettingTimeout && !isPagePending) {
    processMainEncoders(now);  // 4개 인코더 회전 및 스무딩
    handleGlobalButton(now);   // 글로벌 버튼 단독 동작 (설정 중엔 무시됨)
    updateUIDisplay(now);      // 일반 UI 점진적 갱신
    handleVisualFlash(now);    // LED 깜빡임 타이머
  }
}
